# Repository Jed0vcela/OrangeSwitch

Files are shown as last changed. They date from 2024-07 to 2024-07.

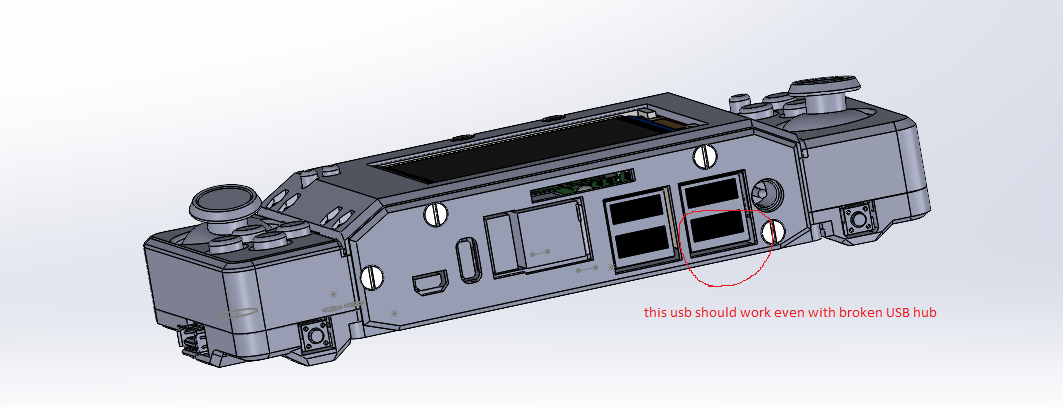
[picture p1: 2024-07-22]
USB that works everytime.png

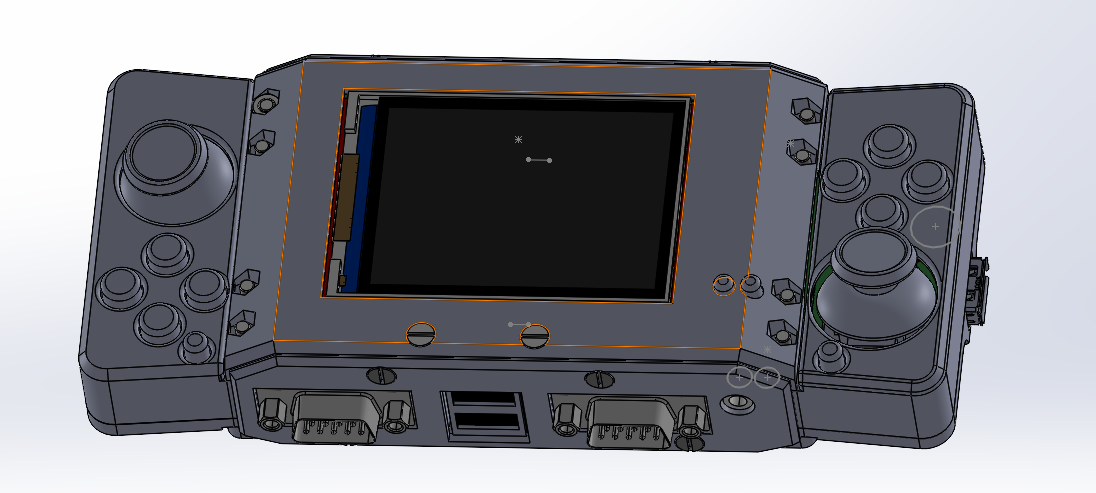
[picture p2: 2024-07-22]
render.png

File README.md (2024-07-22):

# OrangeSwitch
open source game console based on orange Pi 3 zero (2GB ram, 4 core)

reccomended system is Armbian:
  site:
    https://www.armbian.com/orange-pi-zero-3/
    
  direct download:
    https://github.com/armbian/community/releases/download/24.8.0-trunk.399/Armbian_community_24.8.0-trunk.399_Orangepizero3_noble_current_6.6.36_gnome_desktop.img.xz

after downloading, how to install system on SD card:
  https://www.youtube.com/watch?v=UorVt2axGmE

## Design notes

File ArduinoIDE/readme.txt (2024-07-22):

download arduino IDE:
https://www.arduino.cc/en/software

add  <USB.h> and <USBHIDGamepad.h> library to arduino ide. how to add library:
https://support.arduino.cc/hc/en-us/articles/5145457742236-Add-libraries-to-Arduino-IDE

add <esp32> in boardm manager to arduino ide.

To flash program to esp32 you first need to set it to boot0 mode.
That is done by shorting bootsel pins together - for example using piece of wire -
And plugging in USB C cable.
Then upload program and disconnect and connect USB cable to reset ESP32.
After that board should connect as USB gamepad (HID device).

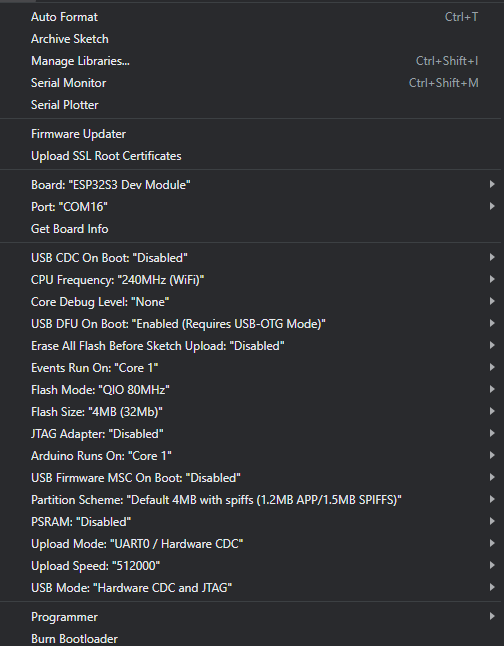
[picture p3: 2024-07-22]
ArduinoIDE/arduino IDE settings.png

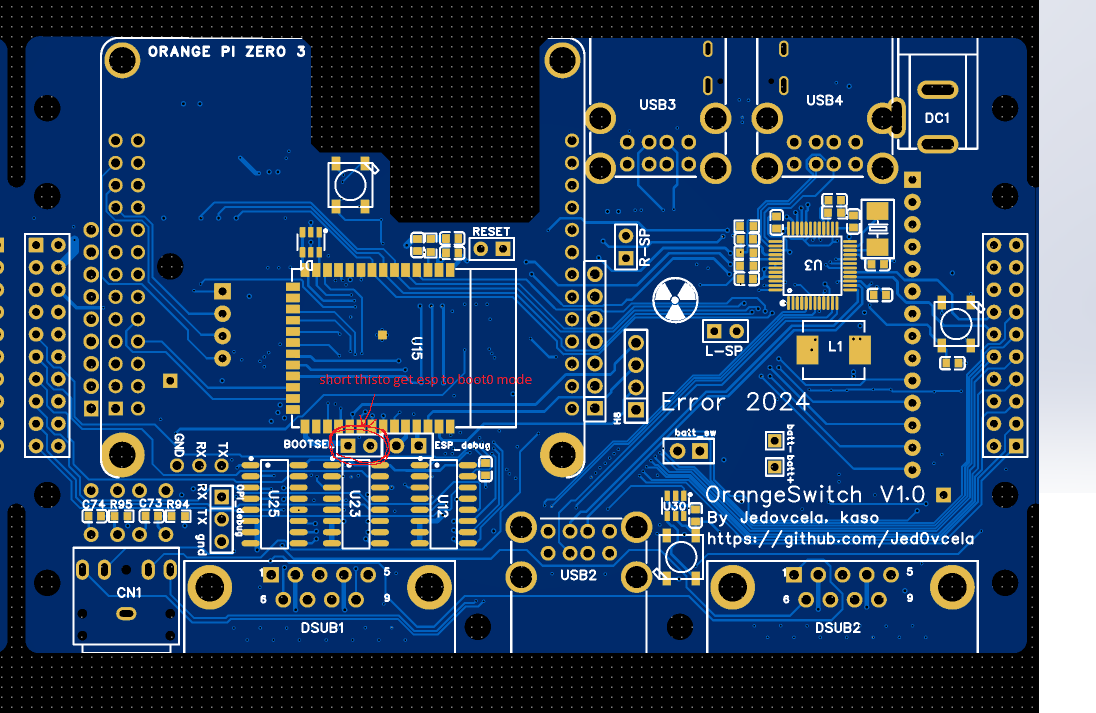
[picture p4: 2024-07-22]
ArduinoIDE/where is bootsel.png

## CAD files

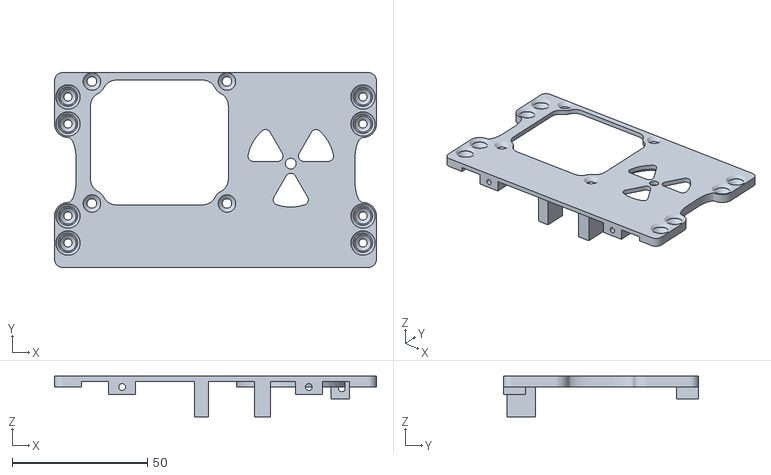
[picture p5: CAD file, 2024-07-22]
STLs/speaker main bottom^orangeSwitch.STL
119.0 x 72.0 x 15.0

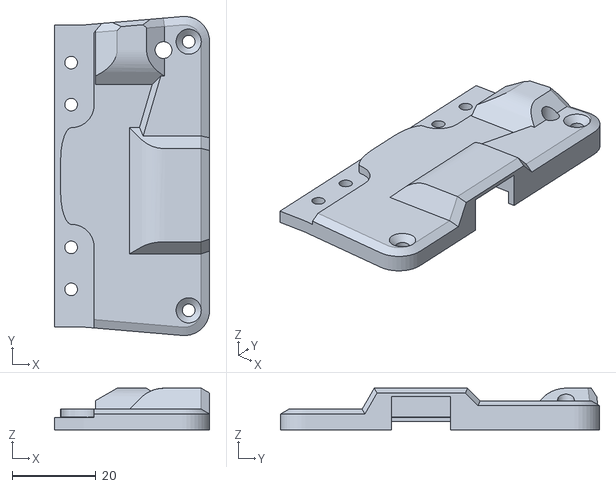
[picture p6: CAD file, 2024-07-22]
STLs/left controller bottom USB^orangeSwitch.STL
37.0 x 76.0 x 9.92

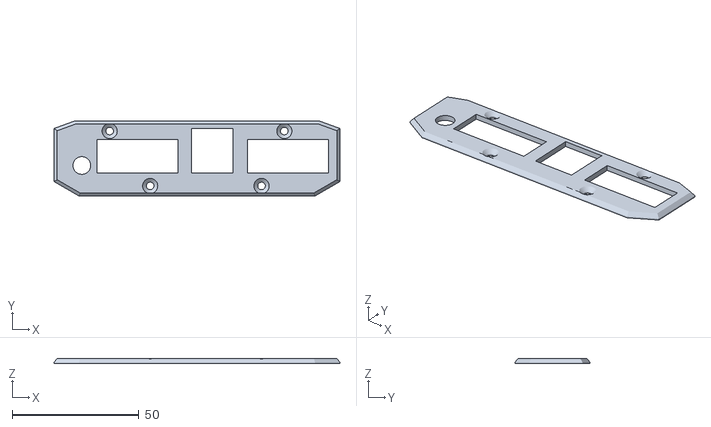
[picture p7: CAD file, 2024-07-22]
STLs/front side plate^orangeSwitch.STL
113.0 x 29.7 x 2.00

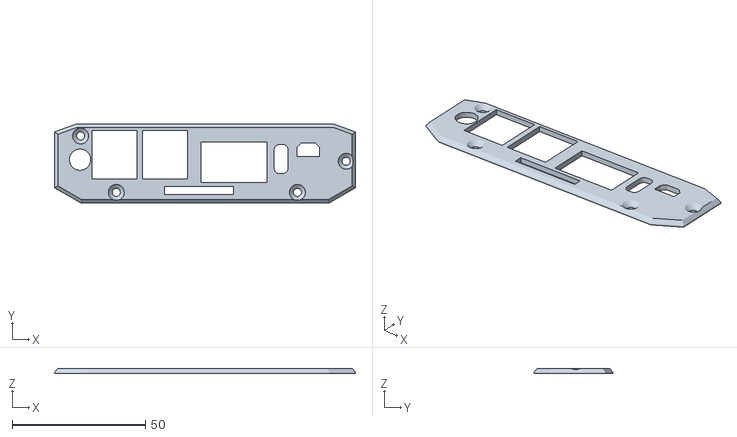
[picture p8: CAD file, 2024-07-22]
STLs/back side plate^orangeSwitch.STL
113.0 x 29.7 x 2.00

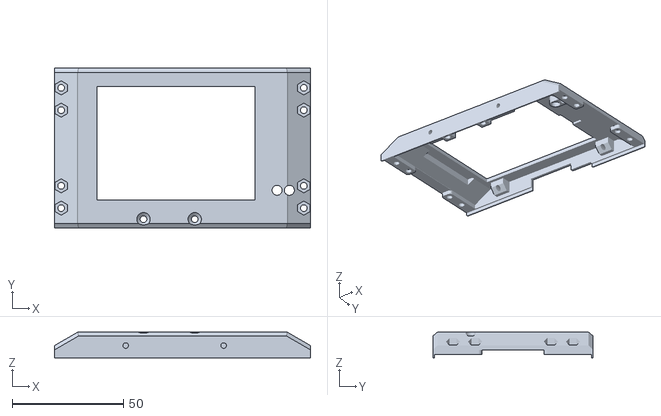
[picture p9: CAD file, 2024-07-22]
STLs/middle top plate^orangeSwitch.STL
115.0 x 72.0 x 11.5

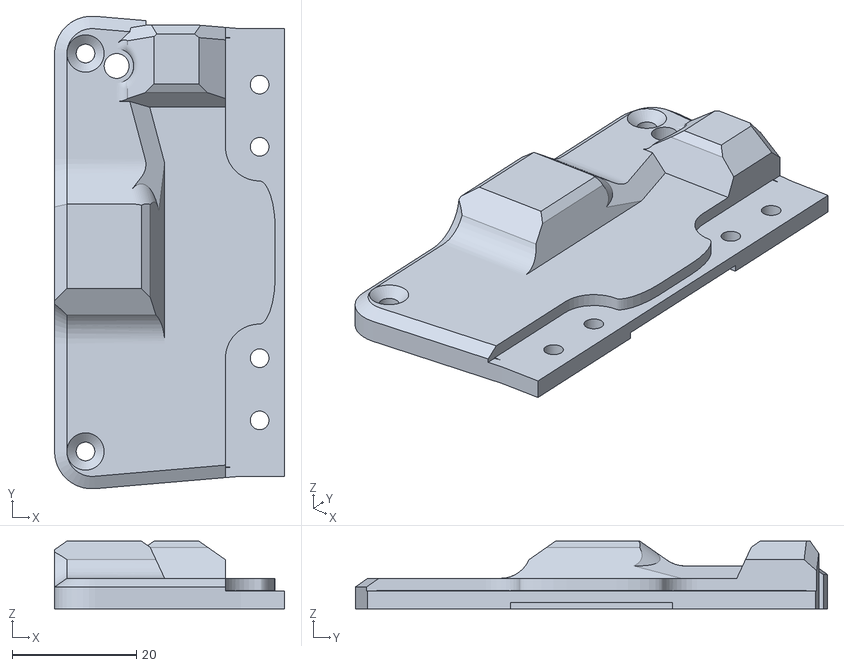
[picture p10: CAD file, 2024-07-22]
STLs/right control bottom with USB.STL
37.0 x 76.0 x 10.9

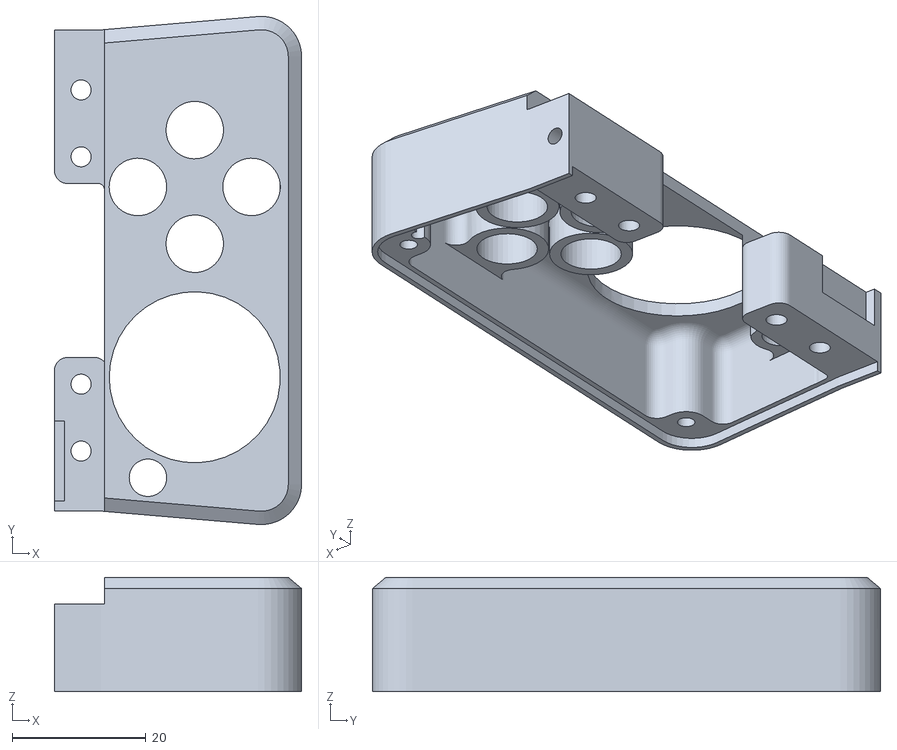
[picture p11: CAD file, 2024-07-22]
STLs/rigt control top^orangeSwitch.STL
37.0 x 76.0 x 17.1

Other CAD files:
STLs/left controller top^orangeSwitch.STL

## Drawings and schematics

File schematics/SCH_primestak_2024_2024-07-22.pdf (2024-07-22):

Orange Pi | 5V supply

### buck 5V supply

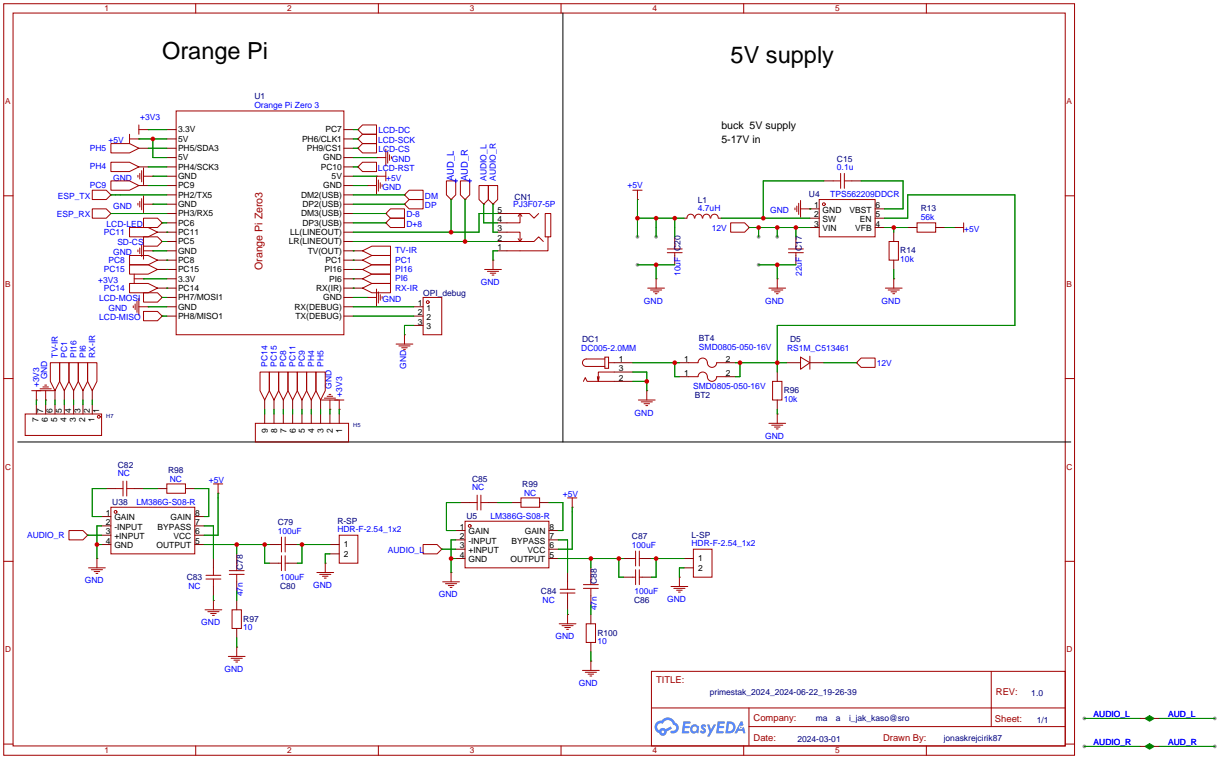
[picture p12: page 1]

### in gamepad schematics

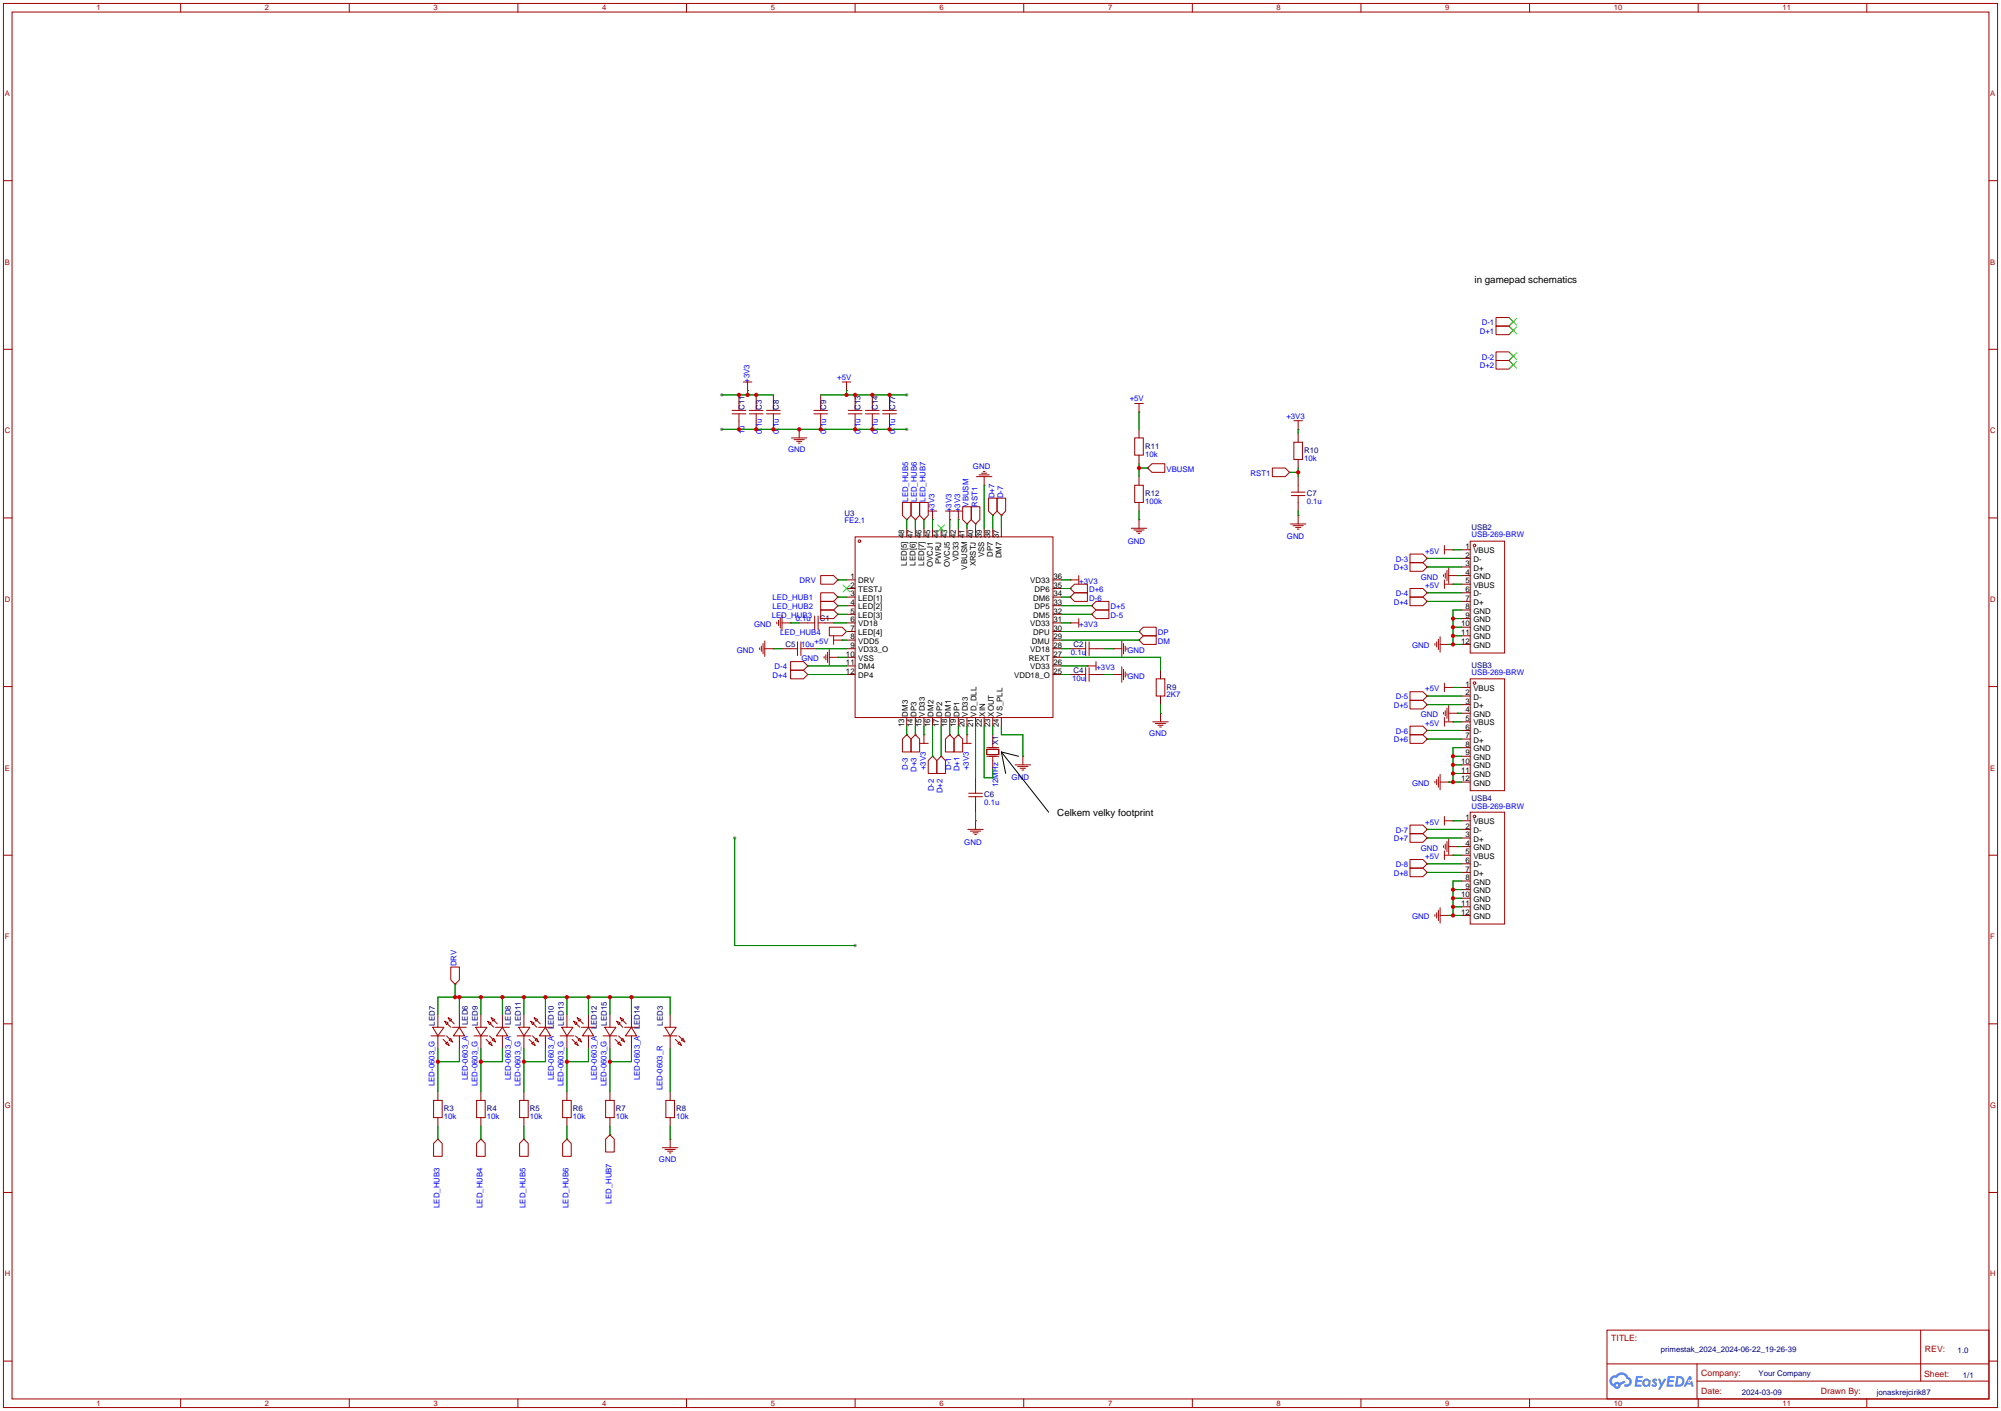
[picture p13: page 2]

### left removable controller

### right removable controller

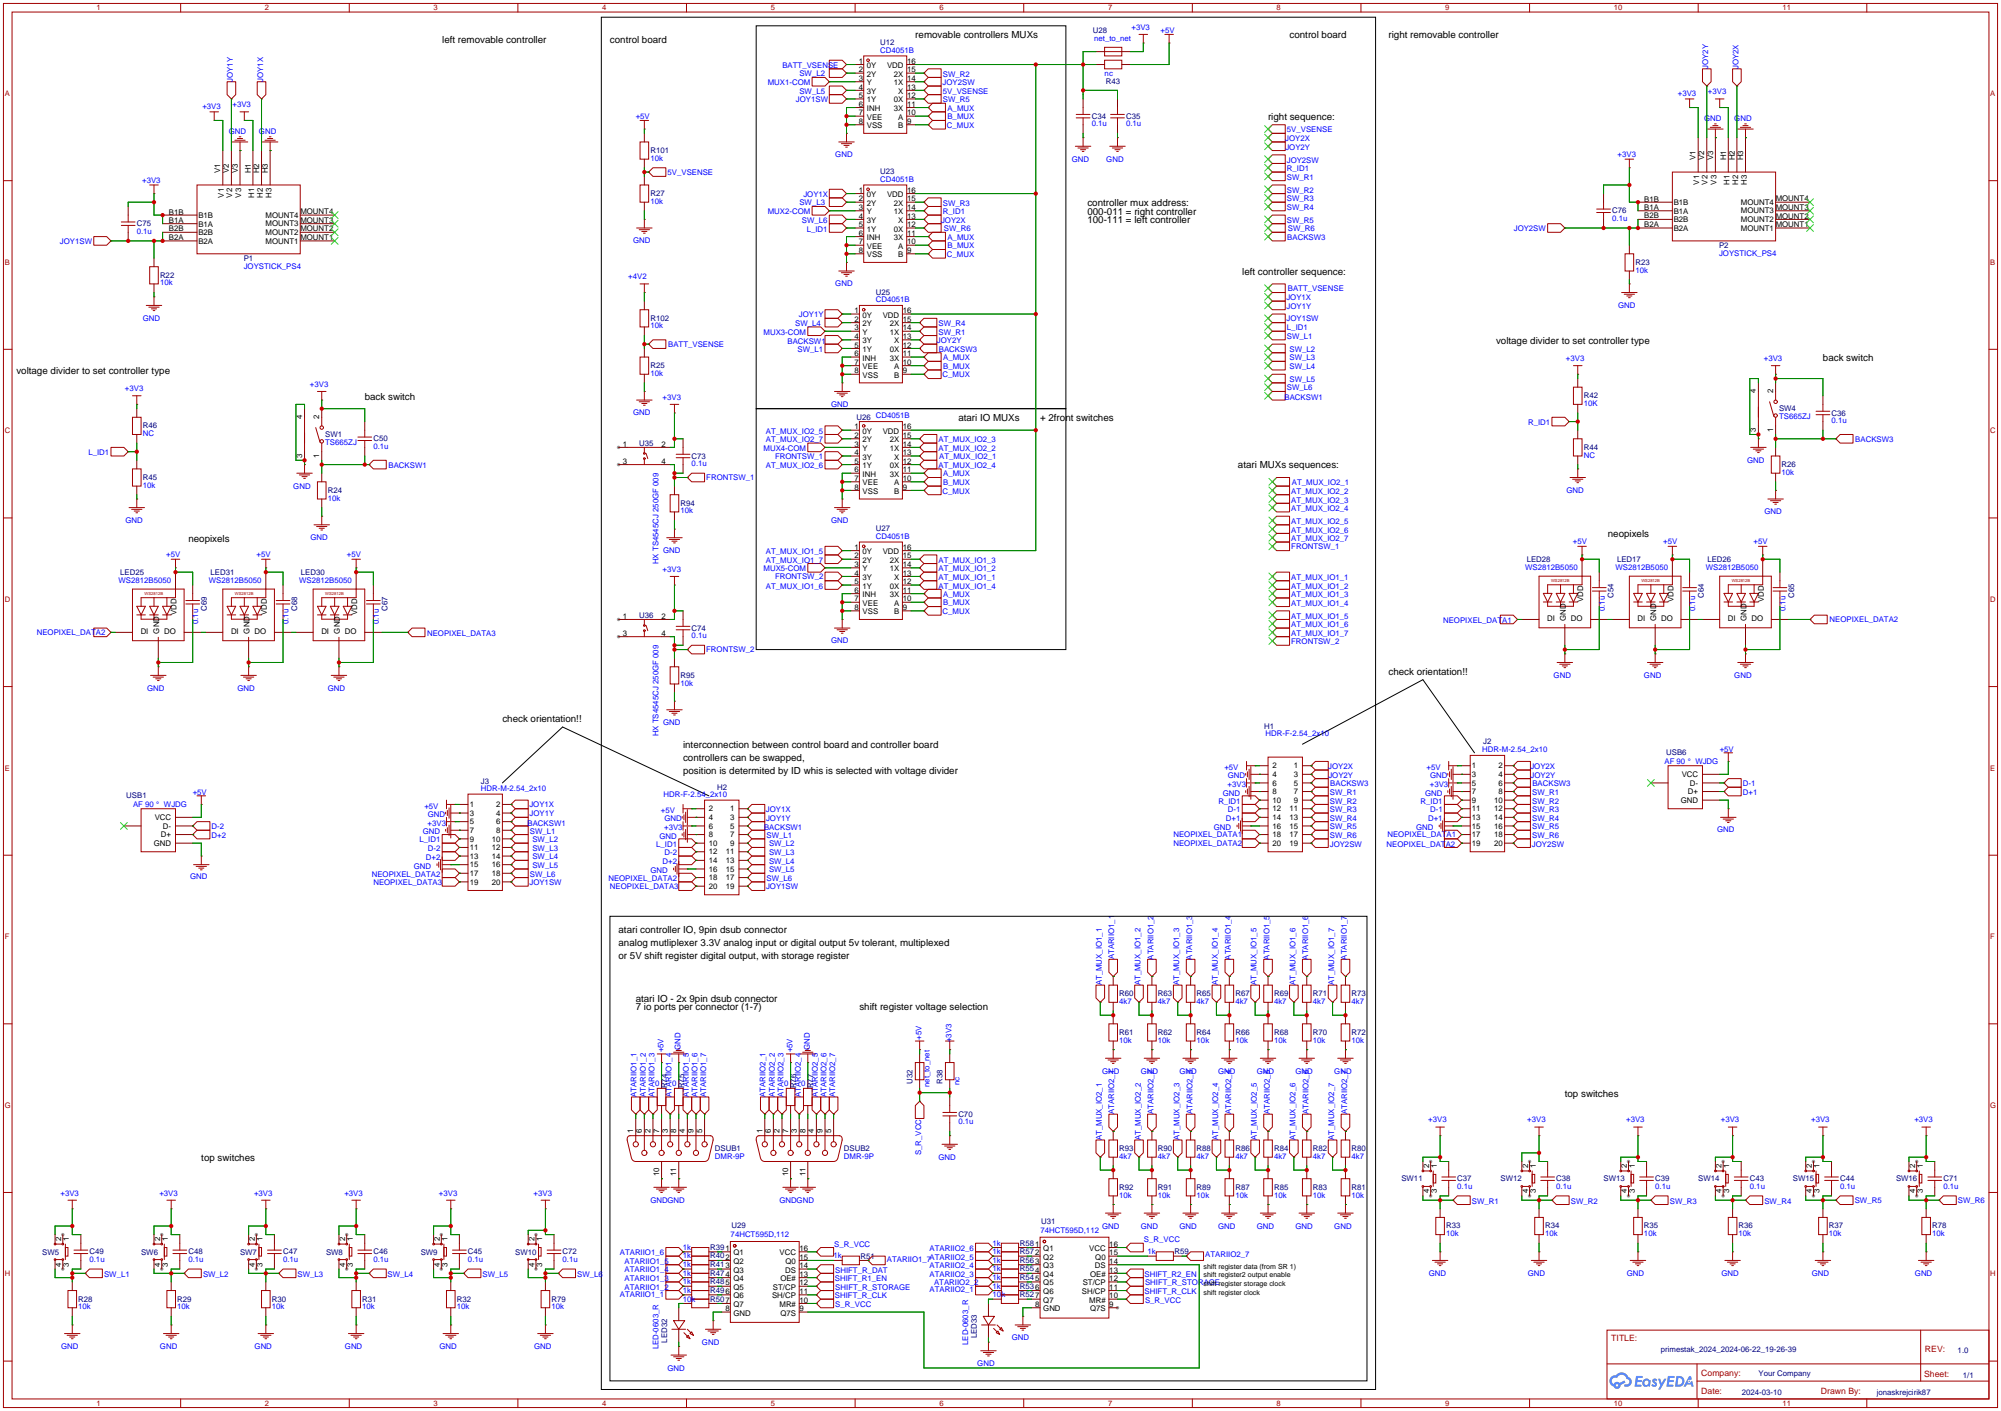
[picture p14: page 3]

voltage divider to set controller type

GND
interconnection between control board and controller board
controllers can be swapped,
position is determited by ID whis is selected with voltage divider

atari controller IO, 9pin dsub connector
analog mutliplexer 3.3V analog input or digital output 5v tolerant, multiplexed
or 5V shift register digital output, with storage register

atari IO - 2x 9pin dsub connector
7 io ports per connector (1-7)

shift register voltage selection

MR# 10 SH/CP 11 ST/CP 12 OE# 13 DS 14 Q0 15 VCC 16

ATARIIO2_7
shift register data (from SR 1)
shift register2 output enable
shift register storage clock

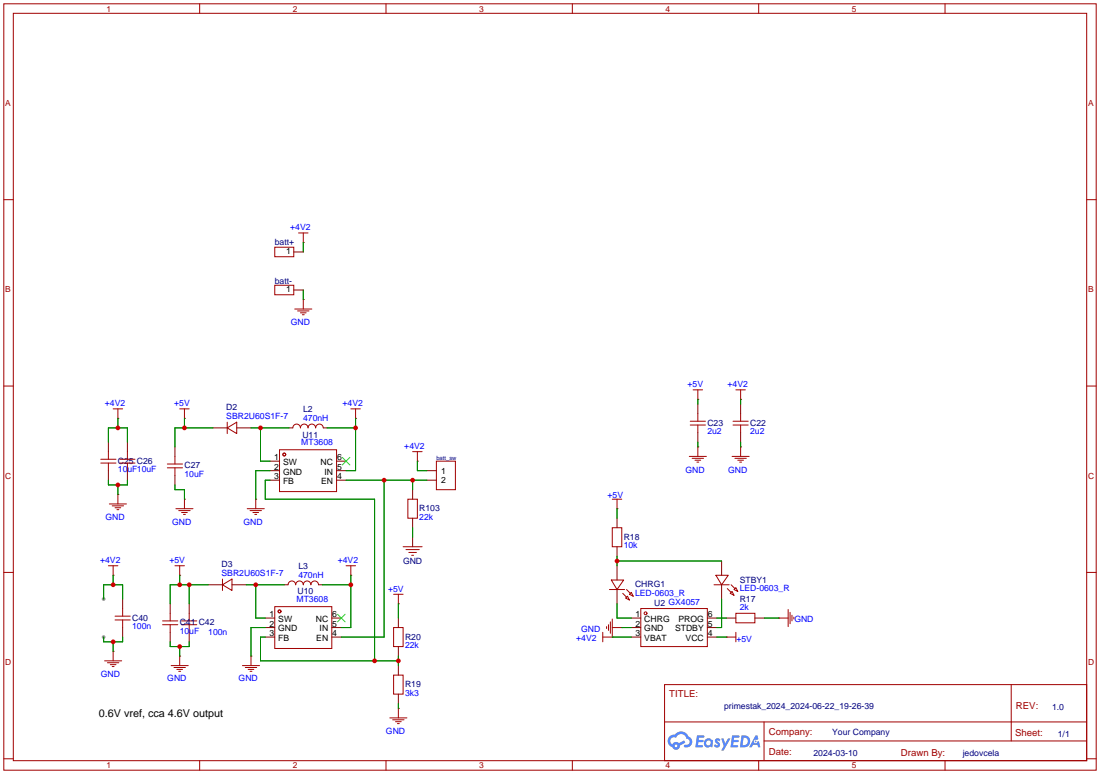
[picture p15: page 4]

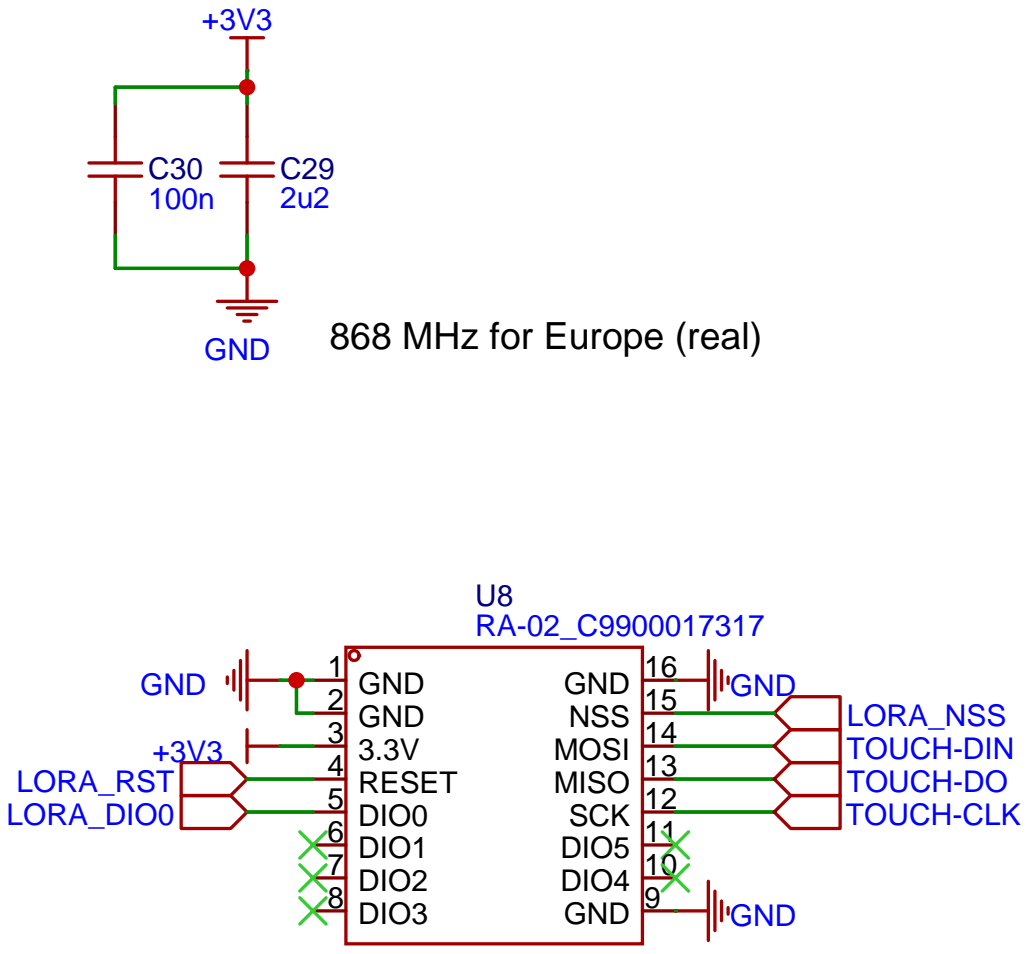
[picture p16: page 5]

868 MHz for Europe (real)

# +3V3 C³² 0.1u

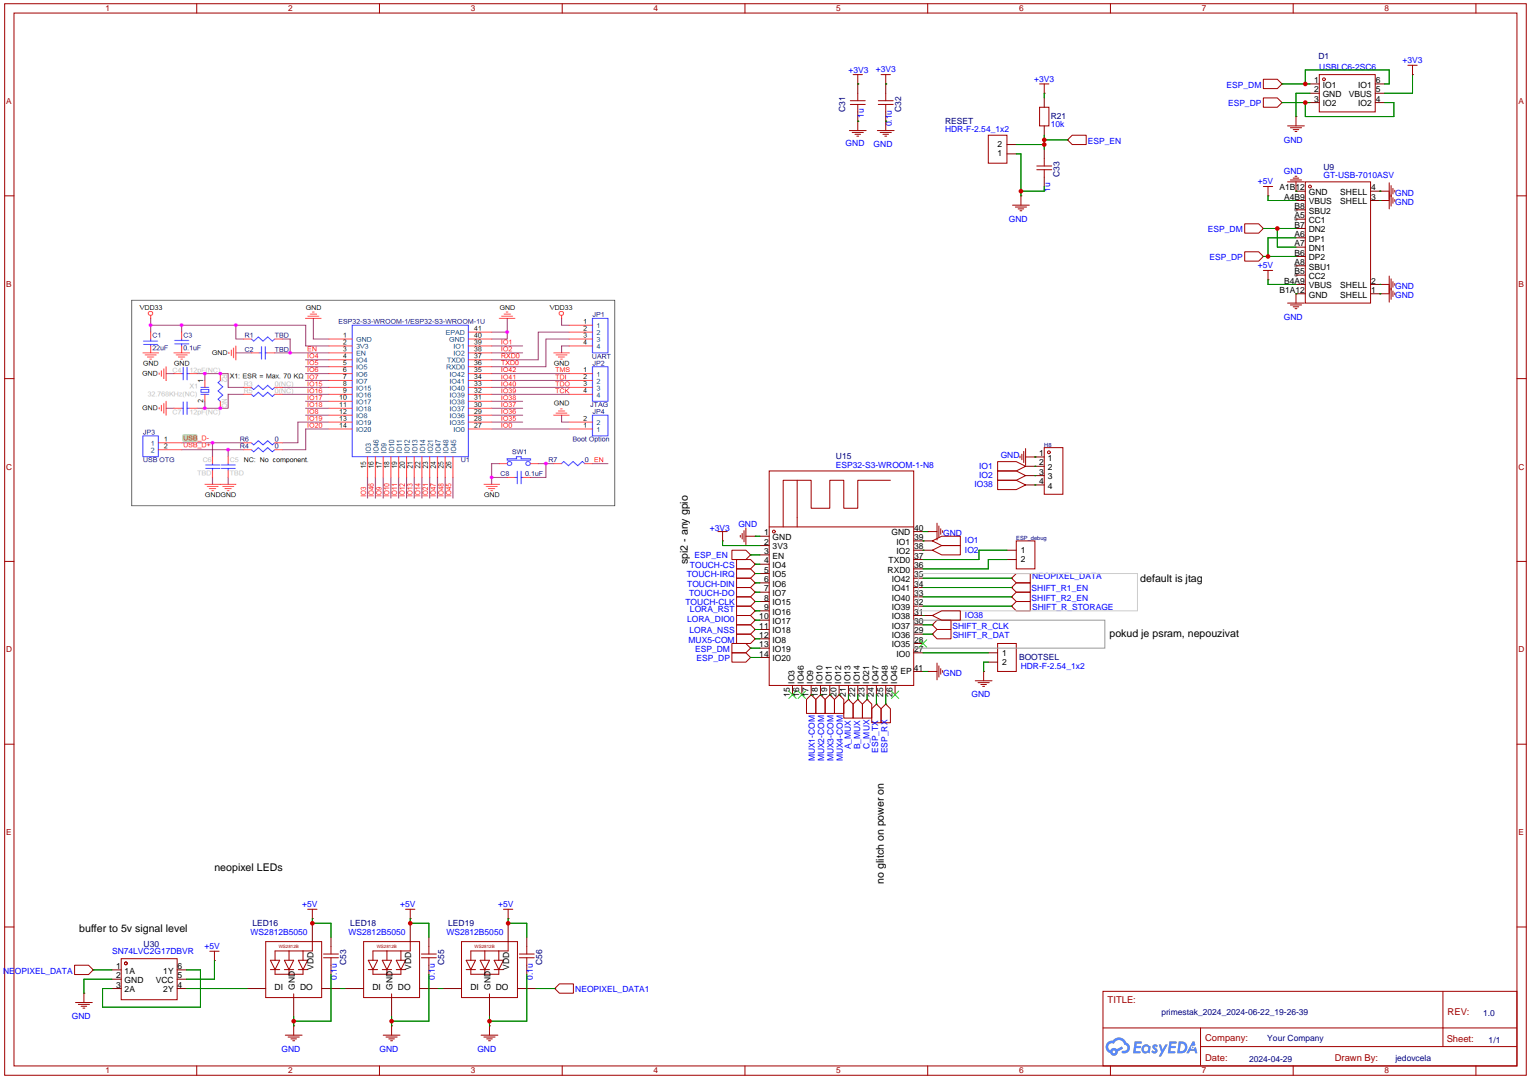
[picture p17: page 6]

pokud je psram, nepouzivat

no glitch on power on

buffer to 5v signal level

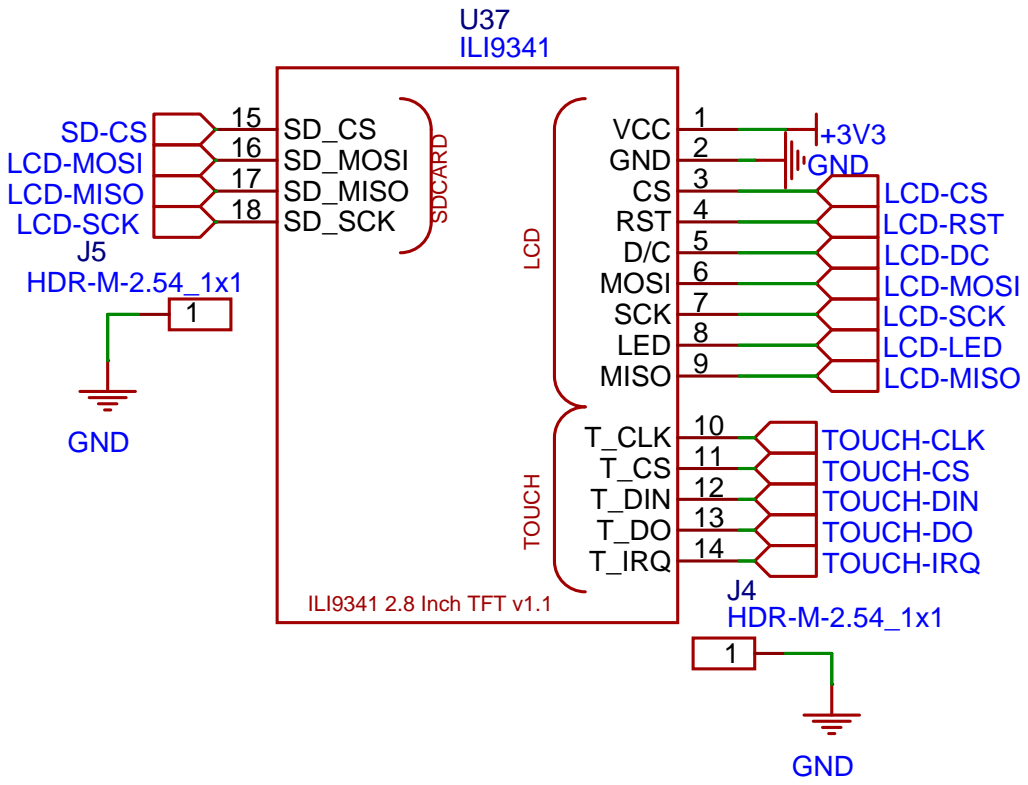
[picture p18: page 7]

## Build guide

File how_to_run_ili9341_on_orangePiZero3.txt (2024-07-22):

to:
cd /boot/dtb/allwinner/overlay

add:
sudo nano sun50i-a64-orangeTFT3.dts

which is:
/dts-v1/;
/plugin/;

/ {
    compatible = "allwinner,sun50i-a64";

    fragment@0 {
        target = <&spi1>;

        __overlay__ {
            status = "okay";

            spidev@0{
                status = "disabled";
            };

            spidev@1{
                status = "disabled";
            };
        };
    };
   fragment@1 {
        target = <&pio>;

        __overlay__ {
            opiz_display_pins: opiz_display_pins {
                pins = "PC14", "PC15"; /*, "PC6"; /*dc,rst,led, dc=pc7,rst=pc10  first two pins interfere with spi initialization – they are random gpio*/
                function = "gpio_out", "gpio_out";
            };
        };
    };

    fragment@2 {
        target = <&spi1>;

        __overlay__ {
        /* needed to avoid dtc warning */
        #address-cells = <1>;
        #size-cells = <0>;
        status = "okay";
        pinctrl-names = "default";
        cs-gpios = <&pio 7 9 0>;
        num-chipselects = <1>;
            opizdisplay: opiz-display@0{
                compatible = "ilitek,ili9341";
                reg = <0>;
                pinctrl-names = "default";
                pinctrl-0 = <&opiz_display_pins>;

                spi-max-frequency = <32000000>;
                rotate = <90>;
                bgr = <0>;
                fps = <30>;
                buswidth = <8>;
                reset-gpios = <&pio 2 10 1>;
                dc-gpios = <&pio 2 7 0>;

                /* don't bind the backlight to the display, we'll access the
                    GPIO pin directly from software */
                /* led-gpios = <&pio 2 6 0>; */

                width = <240>;
                height = <320>;

                debug = <4>;

            };
        };
    };
};

compile with this (shows errors in contrast to next compile method):
sudo dtc -O dtb -o sun50i-a64-orangeTFT3.dtbo sun50i-a64-orangeTFT3.dts 

after that compile with(also adds something to armbianEnv.txt):
sudo armbian-add-overlay sun50i-a64-orangeTFT3.dts

open:
sudo nano /boot/armbianEnv.txt

which should look like:
verbosity=1
bootlogo=true
console=both
disp_mode=1920x1080p60
overlay_prefix=sun50i-a64
rootdev=UUID=b3895e91-ac88-4fe0-9a25-5a2f3e7d3432
rootfstype=ext4
user_overlays=sun50i-a64-orangeTFT3
overlay=orangeTFT3
usbstoragequirks=0x2537:0x1066:u,0x2537:0x1068:u

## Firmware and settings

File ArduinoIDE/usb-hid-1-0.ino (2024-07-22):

#include "USB.h"
#include "USBHIDGamepad.h"
USBHIDGamepad Gamepad;

const int buttonPin = 0;
const int mux1 = 9;
const int mux2 = 10;
const int mux3 = 11;
const int A = 13;
const int B = 14;
const int C = 21;
int previousButtonState = HIGH;

void setup() {
  pinMode(buttonPin, INPUT_PULLUP);
  pinMode(mux1, INPUT_PULLDOWN);  //imputs from analog switches
  pinMode(mux2, INPUT_PULLDOWN);
  pinMode(mux3, INPUT_PULLDOWN);

  pinMode(A, OUTPUT);   //analog switch adress select pins
  pinMode(B, OUTPUT);
  pinMode(C, OUTPUT);

  Gamepad.begin();
  USB.begin();
  //analogSetWidth(12);
}

void loop() {
  static uint8_t padID = 0;
  static long lastPress = 0;
  uint16_t analogMux2;
  uint16_t analogMux3;

  digitalWrite(A, LOW); //hsb
  digitalWrite(B, LOW);
  digitalWrite(C, LOW); //least significant byte
  delay(1);
  analogMux2 = (analogRead(mux2)/16-128);
  analogMux3 = (analogRead(mux3)/16)-128;
  Gamepad.leftStick(analogMux2, analogMux3); // X Axis, Y Axis
  //Gamepad.leftStick(analogRead(mux2), (analogRead(mux3)); // X Axis, Y Axis
  delay(1);

  digitalWrite(A, LOW);
  digitalWrite(B, LOW);
  digitalWrite(C, HIGH);
  delay(1);
  analogMux2 = analogRead(mux2)/16-128;
  analogMux3 = analogRead(mux3)/16-128;
  Gamepad.rightStick(analogMux2, analogMux3);
  //Gamepad.rightStick(analogRead(mux2), (analogRead(mux3)); // X Axis, Y Axis
  delay(1);

  digitalWrite(A, LOW);
  digitalWrite(B, HIGH);
  digitalWrite(C, LOW);
  delay(1);

  if(analogRead(mux1)>800){
    Gamepad.pressButton(1);
  }
  else{
    Gamepad.releaseButton(1);
    }

  if(analogRead(mux2)>800){
    Gamepad.pressButton(2);
    }
  else{
    Gamepad.releaseButton(2);
  }

  if(analogRead(mux3)>800){
    Gamepad.pressButton(3);
    }
  else{
    Gamepad.releaseButton(3);
  }

  digitalWrite(A, LOW);
  digitalWrite(B, HIGH);
  digitalWrite(C, HIGH);
  delay(1);
  if(analogRead(mux1)>800){
    Gamepad.pressButton(4);
  }
  else{
    Gamepad.releaseButton(4);
    }

  if(analogRead(mux2)>800){
    Gamepad.pressButton(5);
    }
  else{
    Gamepad.releaseButton(5);
  }

  if(analogRead(mux3)>800){
    Gamepad.pressButton(6);
    }
  else{
    Gamepad.releaseButton(6);
  }

  digitalWrite(A, HIGH);
  digitalWrite(B, LOW);
  digitalWrite(C, LOW);
  delay(1);
  if(analogRead(mux1)>800){
    Gamepad.pressButton(7);
  }
  else{
    Gamepad.releaseButton(7);
    }

  if(analogRead(mux2)>800){
    Gamepad.pressButton(8);
    }
  else{
    Gamepad.releaseButton(8);
  }

  if(analogRead(mux3)>800){
    Gamepad.pressButton(9);
    }
  else{
    Gamepad.releaseButton(9);
  }

  digitalWrite(A, HIGH);
  digitalWrite(B, LOW);
  digitalWrite(C, HIGH);
  delay(1);
  if(analogRead(mux1)>800){
    Gamepad.pressButton(10);
  }
  else{
    Gamepad.releaseButton(10);
    }

  if(analogRead(mux2)>800){
    Gamepad.pressButton(11);
    }
  else{
    Gamepad.releaseButton(11);
  }

  if(analogRead(mux3)>800){
    Gamepad.pressButton(12);
    }
  else{
    Gamepad.releaseButton(12);
  }

  digitalWrite(A, HIGH);
  digitalWrite(B, HIGH);
  digitalWrite(C, LOW);
  delay(1);
  if(analogRead(mux1)>800){
    Gamepad.pressButton(13);
  }
  else{
    Gamepad.releaseButton(13);
    }

  if(analogRead(mux2)>800){
    Gamepad.pressButton(14);
    }
  else{
    Gamepad.releaseButton(14);
  }

  if(analogRead(mux3)>800){
    Gamepad.pressButton(15);
    }
  else{
    Gamepad.releaseButton(15);
  }

  digitalWrite(A, HIGH);
  digitalWrite(B, HIGH);
  digitalWrite(C, HIGH);
  delay(1);
  if(analogRead(mux1)>800){
    Gamepad.pressButton(16);
  }
  else{
    Gamepad.releaseButton(16);
    }

  if(analogRead(mux2)>800){
    Gamepad.pressButton(17);
    }
  else{
    Gamepad.releaseButton(17);
  }

  if(analogRead(mux3)>800){
    Gamepad.pressButton(18);
    }
  else{
    Gamepad.releaseButton(18);
  }
}
